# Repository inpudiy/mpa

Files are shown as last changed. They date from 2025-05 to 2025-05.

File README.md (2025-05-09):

# MPA

MPA is a 42-key split keyboard built on the CHOC V1 platform using Chocfox spacing.

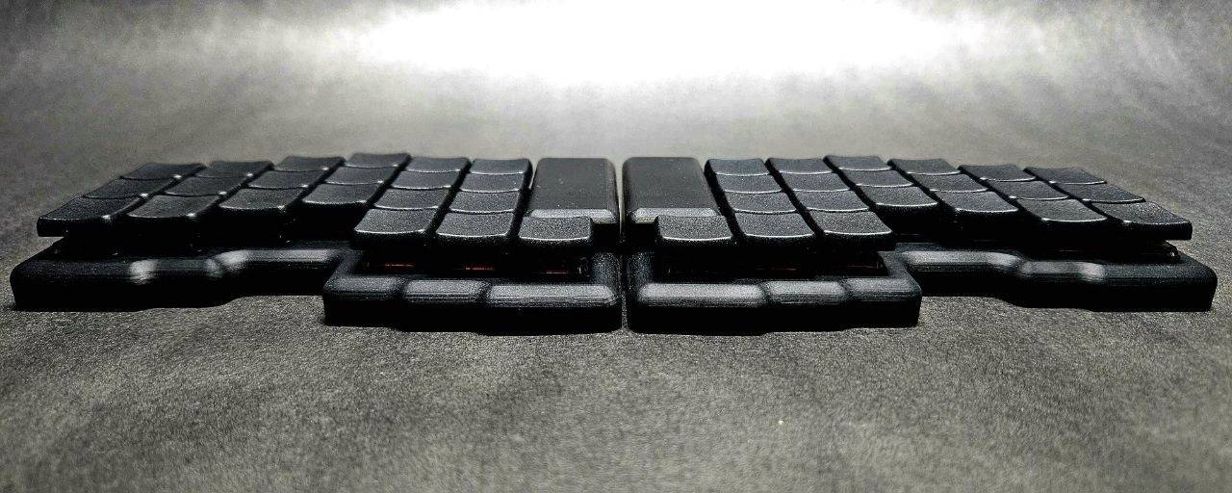
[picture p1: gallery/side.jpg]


[Build Guide](https://github.com/inpudiy/mpa/blob/main/build_guide.md) - [ZMK Firmware](https://github.com/inpudiy/mpa_zmk-config/releases)

## Features

- Supports Chocfox spacing (17.5 × 17.5 mm)  
- Optimized for wireless: hardware power switch, reset button, battery solder pads, no LEDs, and ZMK firmware  
- 42-key layout with an aggressive column-stagger inspired by the Jian keyboard  
- CHOC V1 switches only  
- Pro Micro format microcontroller Compatible with hot-swap installation  
- 3D-printed case  

---

## Bill of Materials (BOM)

| Component | Qty |
| --- | --- |
| Microcontroller: nRFMicro / Super Mini nRF52840 / nice!nano  | 2 |
| Power switch: SUNGMUN BSI-10H | 2 |
| 301230 battery | 2 |
| Turtle Switch SMD 2-pin (3 × 4 × 2 mm) | 2 |
| Silicone bumpers (6 × 2 mm) | 4 |
| Pin Header Female 13 pin (2.54mm) | 4 | 
| Plastic heat-set insert nut M2 (OD 3.2 mm, length 3 mm) | 14  |
| Countersunk head screw M2 (length 4 mm) | 14  |
| PG1350 hot-swap socket | 42  |
| Diode 1N4148W (SOD-323) | 42  |
| CHOC V1 switches | 42  |
| Chocfox 1U keycaps | 42  |

## PCB Image

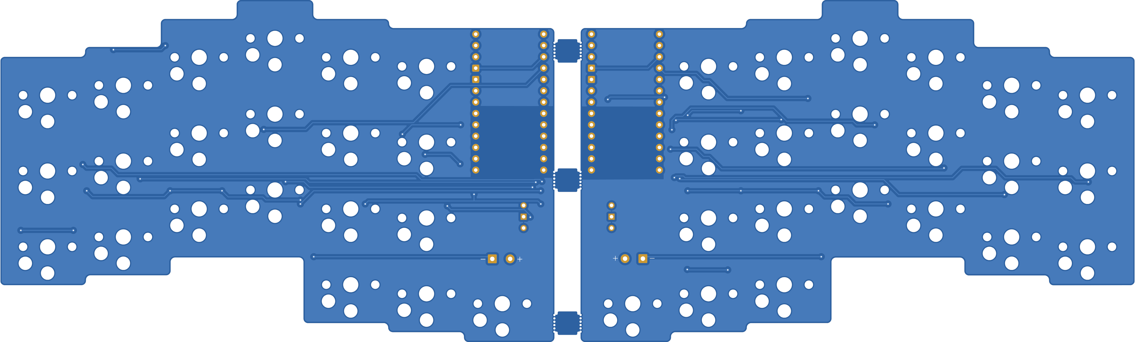
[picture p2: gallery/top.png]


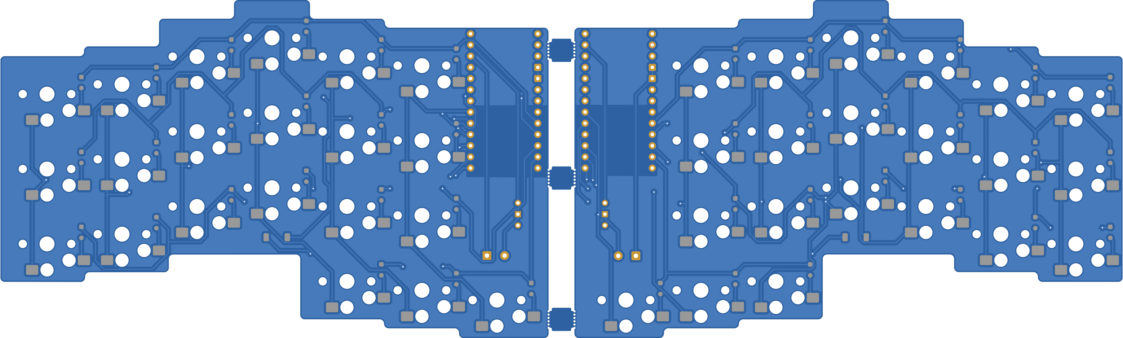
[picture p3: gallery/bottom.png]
Bottom


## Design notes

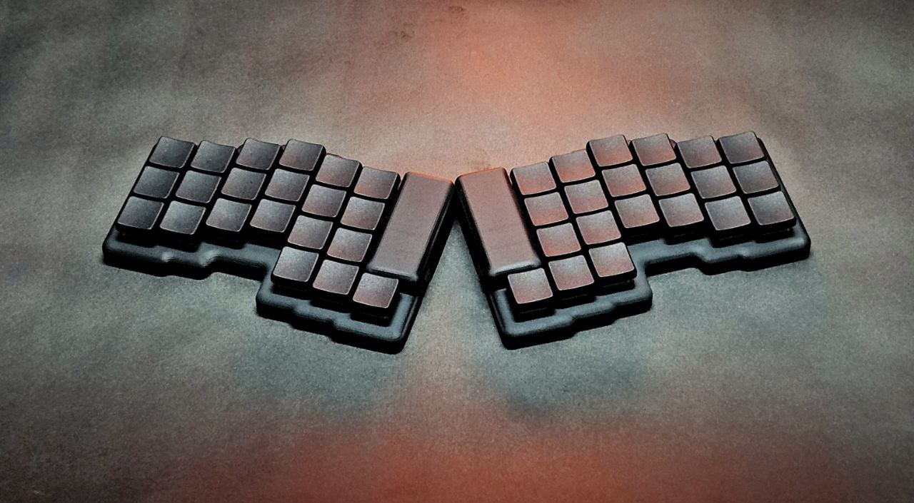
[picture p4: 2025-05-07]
gallery/top.jpg

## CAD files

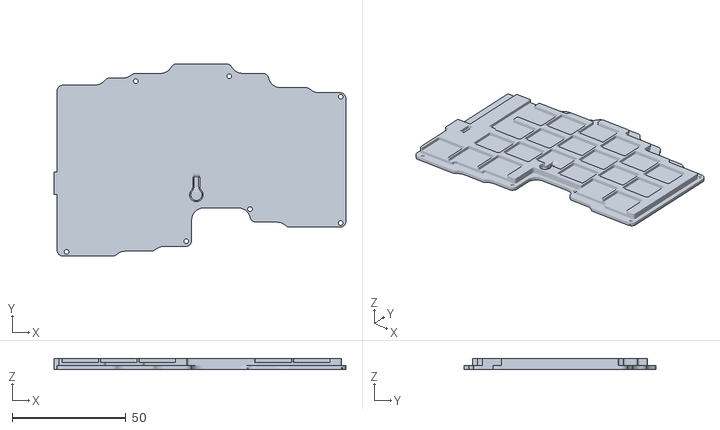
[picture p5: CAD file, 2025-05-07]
case/bottomRight.stl
128.6 x 84.7 x 4.70

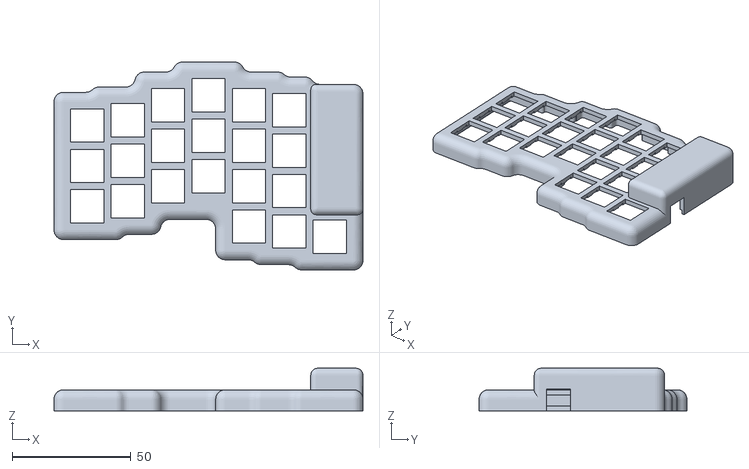
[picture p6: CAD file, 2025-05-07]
case/topLeft.stl
130.0 x 87.4 x 17.9

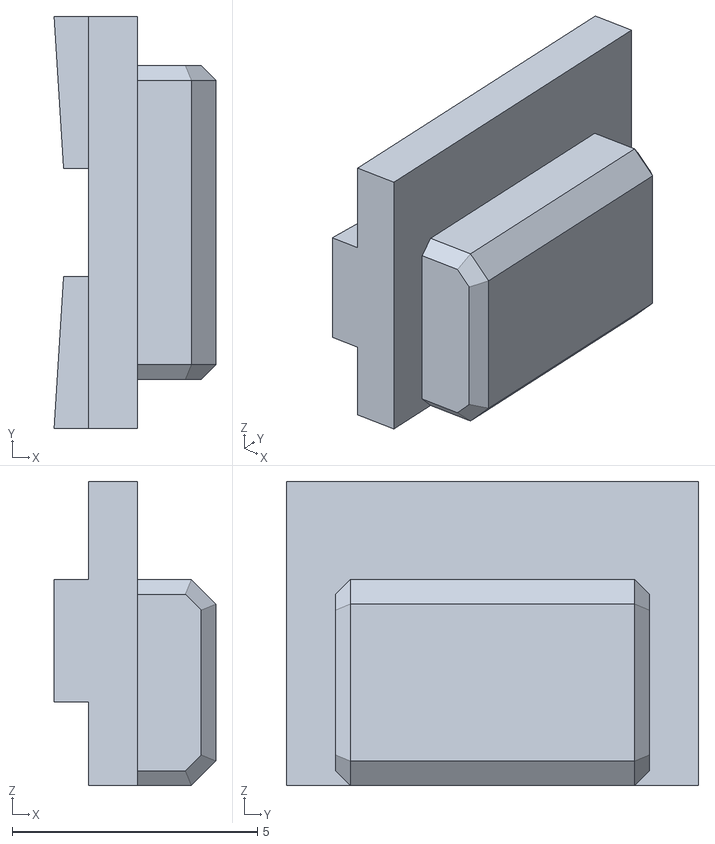
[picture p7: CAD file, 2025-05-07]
case/powerslide.stl
3.30 x 8.40 x 6.20

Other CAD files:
case/topRight.stl
case/bottomLeft.stl

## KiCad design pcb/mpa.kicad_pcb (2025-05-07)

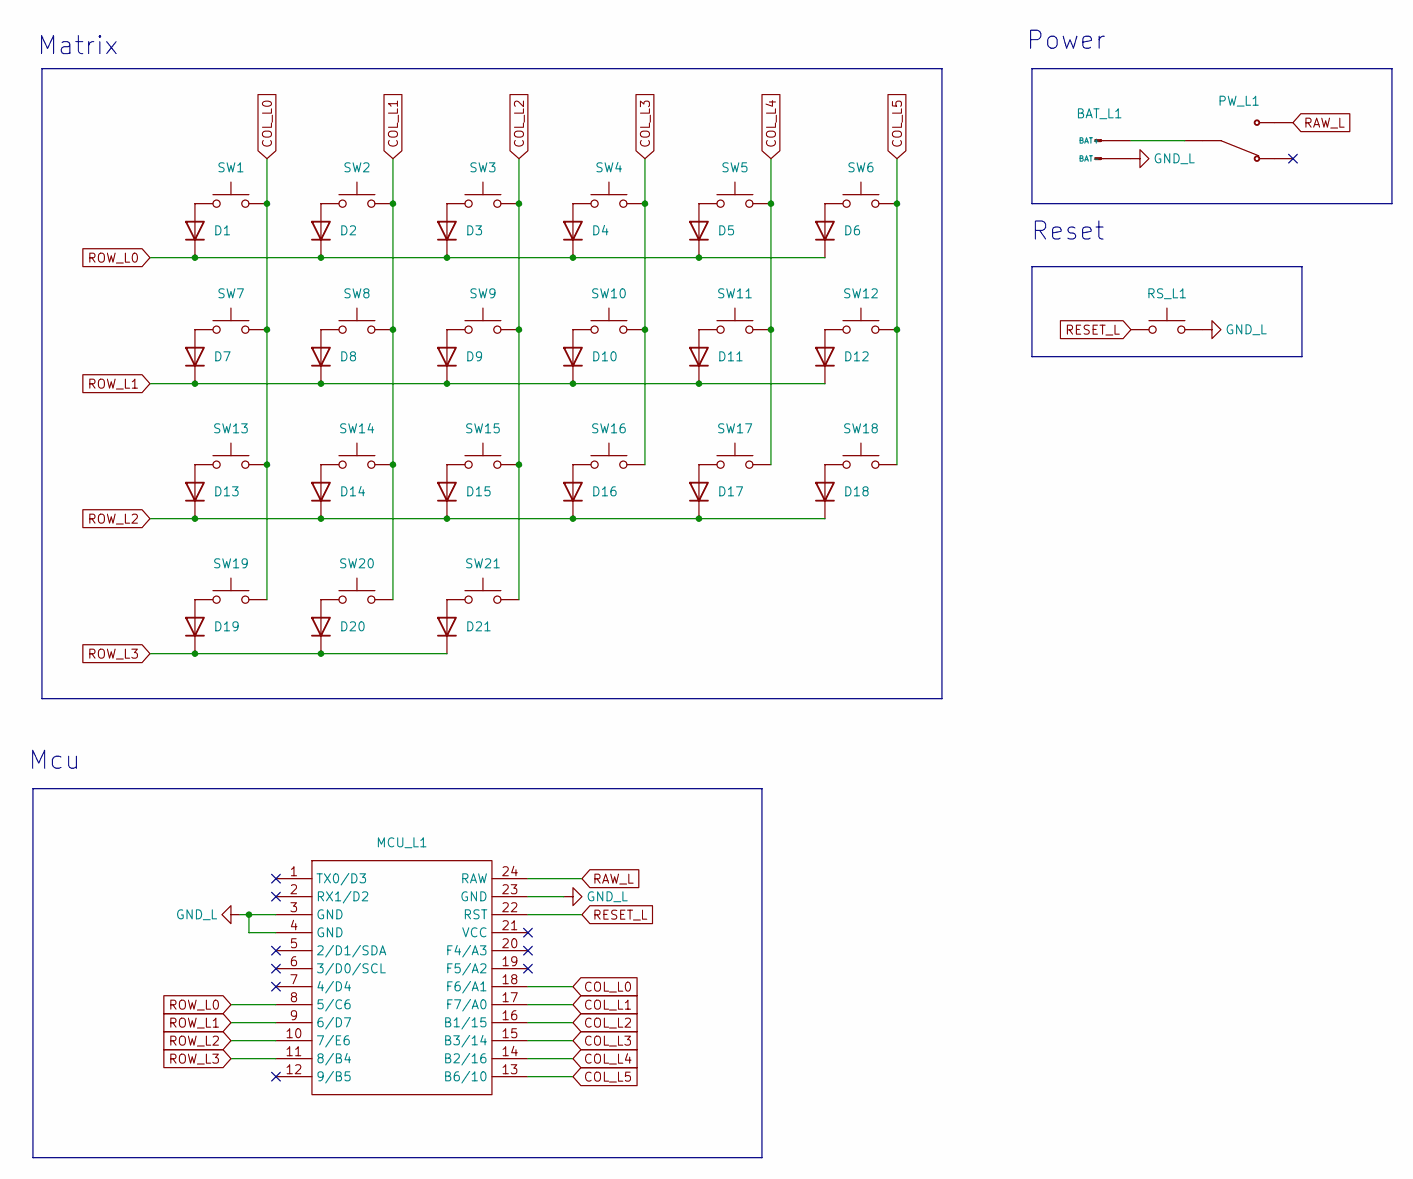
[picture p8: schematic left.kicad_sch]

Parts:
BAT_L1: Battery
D1, D2, D3, D4, D5, D6, D7, D8, D9, D10, D11, D12, D13, D14, D15, D16, D17, D18, D19, D20, D21: Diode; SOD323
MCU_L1: ProMicro_NN
PW_L1: BSI-10H
RS_L1: Reset
SW1, SW2, SW3, SW4, SW5, SW6, SW7, SW8, SW9, SW10, SW11, SW12, SW13, SW14, SW15, SW16, SW17, SW18, SW19, SW20, SW21: Kailh PG1350

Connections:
COL_L0: MCU_L1.18 (F6/A1), SW1.2, SW7.2, SW13.2, SW19.2
COL_L1: MCU_L1.17 (F7/A0), SW2.2, SW8.2, SW14.2, SW20.2
COL_L2: MCU_L1.16 (B1/15), SW3.2, SW9.2, SW15.2, SW21.2
COL_L3: MCU_L1.15 (B3/14), SW4.2, SW10.2, SW16.2
COL_L4: MCU_L1.14 (B2/16), SW5.2, SW11.2, SW17.2
COL_L5: MCU_L1.13 (B6/10), SW6.2, SW12.2, SW18.2
GND_L: BAT_L1.2 (BAT-), MCU_L1.3 (GND), MCU_L1.4 (GND), MCU_L1.23 (GND), RS_L1.2
unnamed: BAT_L1.1 (BAT+), PW_L1.1
unnamed: D1.2 (A), SW1.1
unnamed: D2.2 (A), SW2.1
unnamed: D3.2 (A), SW3.1
unnamed: D4.2 (A), SW4.1
unnamed: D5.2 (A), SW5.1
unnamed: D6.2 (A), SW6.1
unnamed: D7.2 (A), SW7.1
unnamed: D8.2 (A), SW8.1
unnamed: D9.2 (A), SW9.1
unnamed: D10.2 (A), SW10.1
unnamed: D11.2 (A), SW11.1
unnamed: D12.2 (A), SW12.1
unnamed: D13.2 (A), SW13.1
unnamed: D14.2 (A), SW14.1
unnamed: D15.2 (A), SW15.1
unnamed: D16.2 (A), SW16.1
unnamed: D17.2 (A), SW17.1
unnamed: D18.2 (A), SW18.1
unnamed: D19.2 (A), SW19.1
unnamed: D20.2 (A), SW20.1
unnamed: D21.2 (A), SW21.1
RAW_L: MCU_L1.24 (RAW), PW_L1.2
RESET_L: MCU_L1.22 (RST), RS_L1.1
ROW_L0: D1.1 (K), D2.1 (K), D3.1 (K), D4.1 (K), D5.1 (K), D6.1 (K), MCU_L1.8 (5/C6)
ROW_L1: D7.1 (K), D8.1 (K), D9.1 (K), D10.1 (K), D11.1 (K), D12.1 (K), MCU_L1.9 (6/D7)
ROW_L2: D13.1 (K), D14.1 (K), D15.1 (K), D16.1 (K), D17.1 (K), D18.1 (K), MCU_L1.10 (7/E6)
ROW_L3: D19.1 (K), D20.1 (K), D21.1 (K), MCU_L1.11 (8/B4)

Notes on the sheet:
Power
Matrix
Reset
Mcu

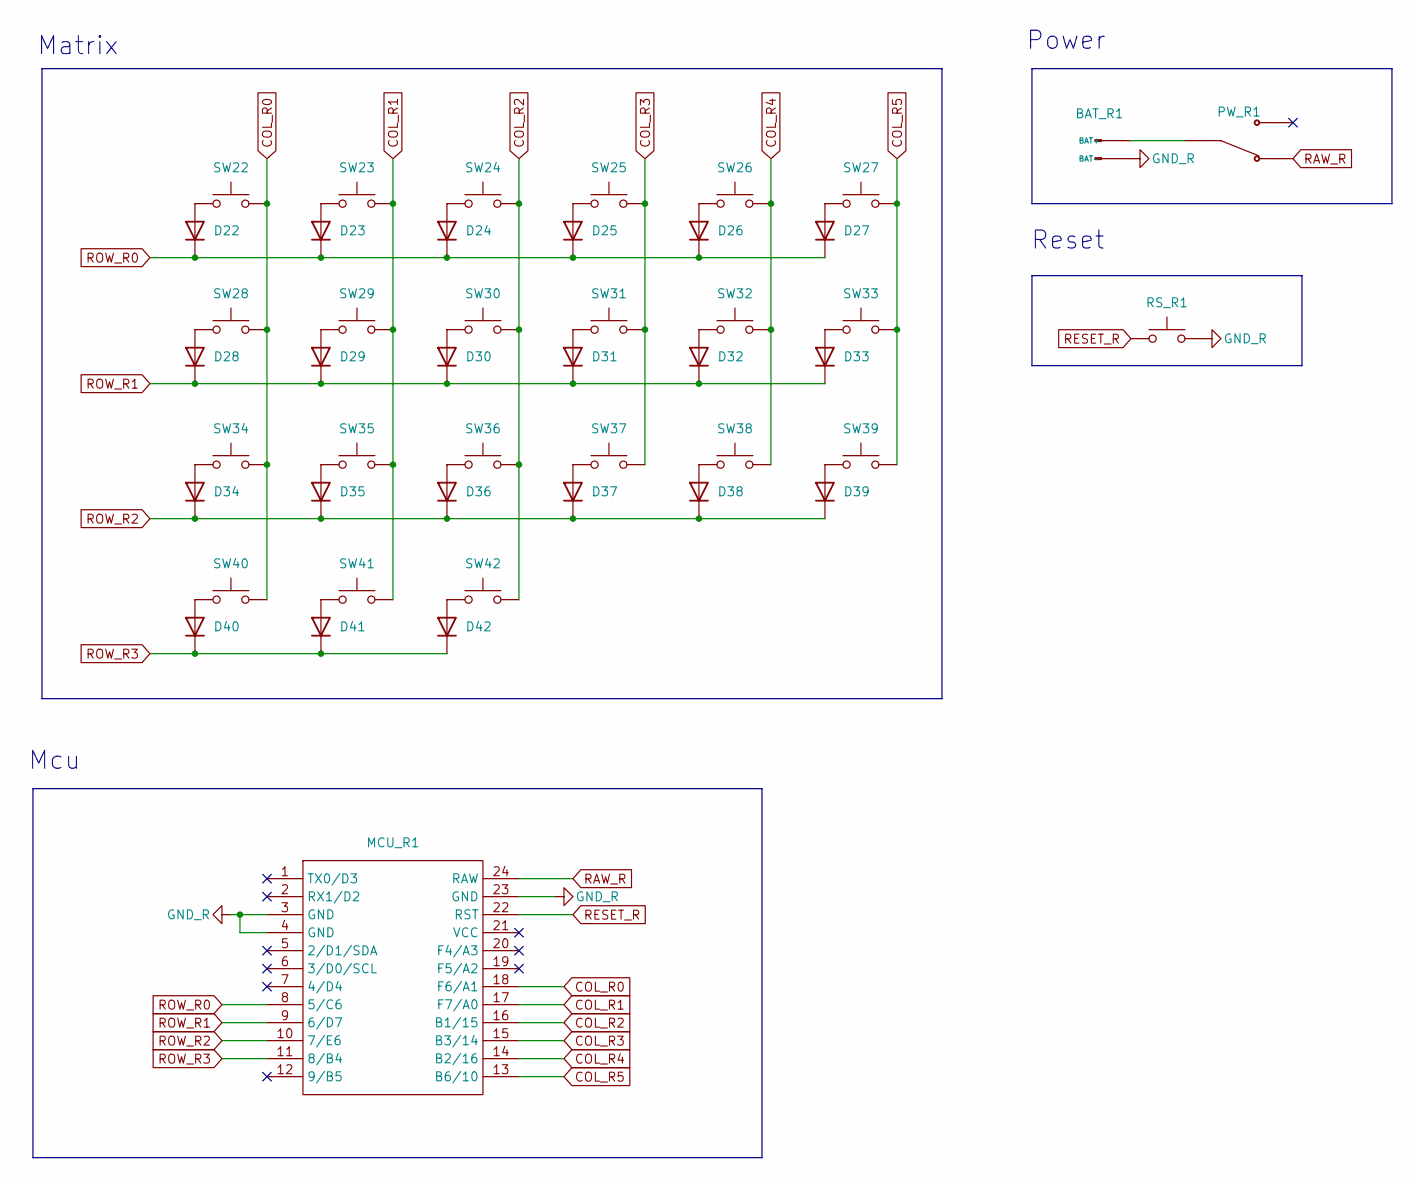
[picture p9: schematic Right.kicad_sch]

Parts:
BAT_R1: Battery
D22, D23, D24, D25, D26, D27, D28, D29, D30, D31, D32, D33, D34, D35, D36, D37, D38, D39, D40, D41, D42: Diode; SOD323
MCU_R1: ProMicro_NN
PW_R1: BSI-10H
RS_R1: Reset
SW22, SW23, SW24, SW25, SW26, SW27, SW28, SW29, SW30, SW31, SW32, SW33, SW34, SW35, SW36, SW37, SW38, SW39, SW40, SW41, SW42: Kailh PG1350

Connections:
COL_R0: MCU_R1.18 (F6/A1), SW22.2, SW28.2, SW34.2, SW40.2
COL_R1: MCU_R1.17 (F7/A0), SW23.2, SW29.2, SW35.2, SW41.2
COL_R2: MCU_R1.16 (B1/15), SW24.2, SW30.2, SW36.2, SW42.2
COL_R3: MCU_R1.15 (B3/14), SW25.2, SW31.2, SW37.2
COL_R4: MCU_R1.14 (B2/16), SW26.2, SW32.2, SW38.2
COL_R5: MCU_R1.13 (B6/10), SW27.2, SW33.2, SW39.2
GND_R: BAT_R1.2 (BAT-), MCU_R1.3 (GND), MCU_R1.4 (GND), MCU_R1.23 (GND), RS_R1.2
unnamed: BAT_R1.1 (BAT+), PW_R1.1
unnamed: D22.2 (A), SW22.1
unnamed: D23.2 (A), SW23.1
unnamed: D24.2 (A), SW24.1
unnamed: D25.2 (A), SW25.1
unnamed: D26.2 (A), SW26.1
unnamed: D27.2 (A), SW27.1
unnamed: D28.2 (A), SW28.1
unnamed: D29.2 (A), SW29.1
unnamed: D30.2 (A), SW30.1
unnamed: D31.2 (A), SW31.1
unnamed: D32.2 (A), SW32.1
unnamed: D33.2 (A), SW33.1
unnamed: D34.2 (A), SW34.1
unnamed: D35.2 (A), SW35.1
unnamed: D36.2 (A), SW36.1
unnamed: D37.2 (A), SW37.1
unnamed: D38.2 (A), SW38.1
unnamed: D39.2 (A), SW39.1
unnamed: D40.2 (A), SW40.1
unnamed: D41.2 (A), SW41.1
unnamed: D42.2 (A), SW42.1
RAW_R: MCU_R1.24 (RAW), PW_R1.3
RESET_R: MCU_R1.22 (RST), RS_R1.1
ROW_R0: D22.1 (K), D23.1 (K), D24.1 (K), D25.1 (K), D26.1 (K), D27.1 (K), MCU_R1.8 (5/C6)
ROW_R1: D28.1 (K), D29.1 (K), D30.1 (K), D31.1 (K), D32.1 (K), D33.1 (K), MCU_R1.9 (6/D7)
ROW_R2: D34.1 (K), D35.1 (K), D36.1 (K), D37.1 (K), D38.1 (K), D39.1 (K), MCU_R1.10 (7/E6)
ROW_R3: D40.1 (K), D41.1 (K), D42.1 (K), MCU_R1.11 (8/B4)

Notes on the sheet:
Mcu
Power
Reset
Matrix

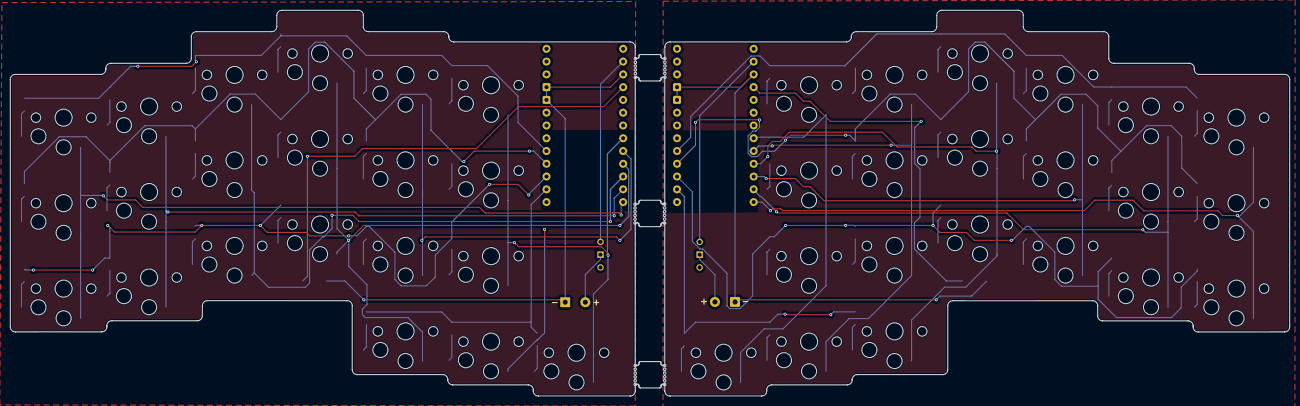
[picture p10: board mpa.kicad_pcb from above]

Board: 2 copper layers, 254.4 x 76.7 mm, 98 parts (0 on the bottom side), 70 nets.

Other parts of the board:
Hole: Hole
Hole#2, Hole#3, Hole#4, Hole#5, Hole#6: Hole

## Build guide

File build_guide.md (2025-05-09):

# Build Guide

This build guide assumes that you already have soldering skills. It will only describe the locations and nuances of component installation

## 1. Break off the chips

There are 3 islands between the board halves, they are not needed during assembly. So gently press on one half of the board to break it in half, and then break off the island from the other half of the board with pliers or any other convenient way

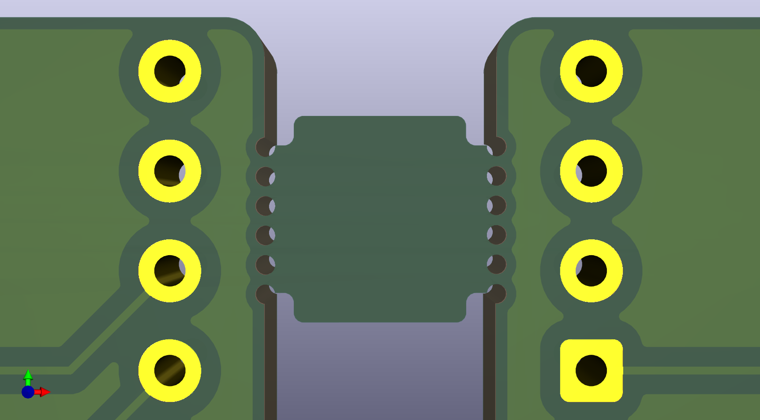
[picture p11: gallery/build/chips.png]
chips


## 2. Diodes

There are 21 diode pads each on the back of the board. Apply flux and place the diodes cathode to square pad and anode to round pad and solder

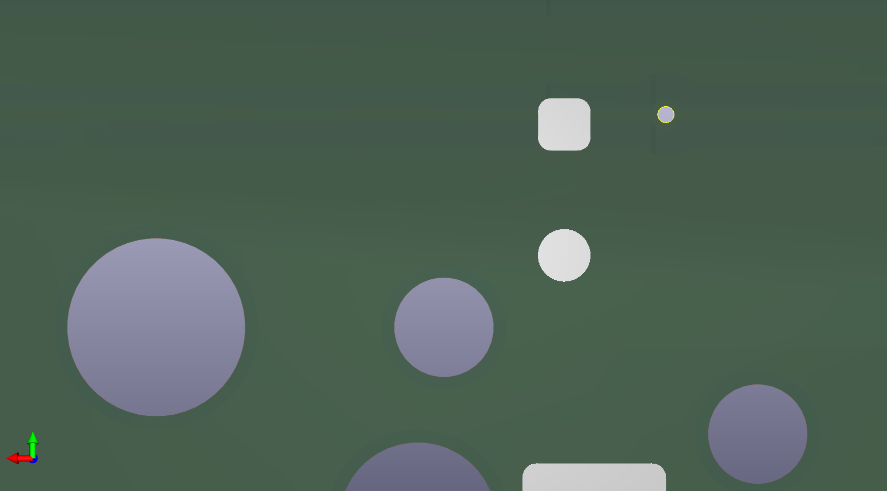
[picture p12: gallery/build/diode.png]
diode


## 3. Hotswap socket

At the bottom of the diodes are the pads for the hotswap sockets. Apply flux and solder them on

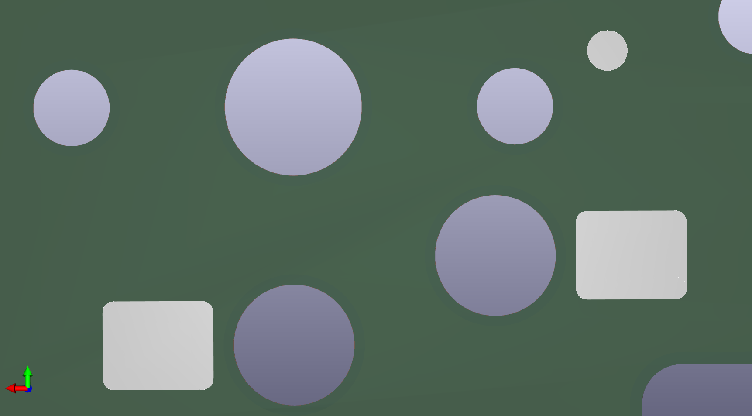
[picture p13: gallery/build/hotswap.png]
hotswap


## 4. Reset button

On the bottom of the board on both halves, install a 3 × 4 × 2 mm Turtle Switch to reset the firmware

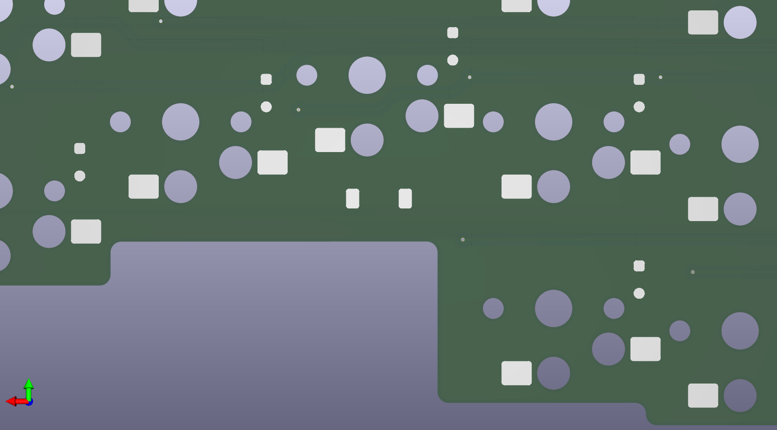
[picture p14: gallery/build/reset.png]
reset


## 5. On-off switch

On the TOP side of the board of both halves, install BSI-10H 

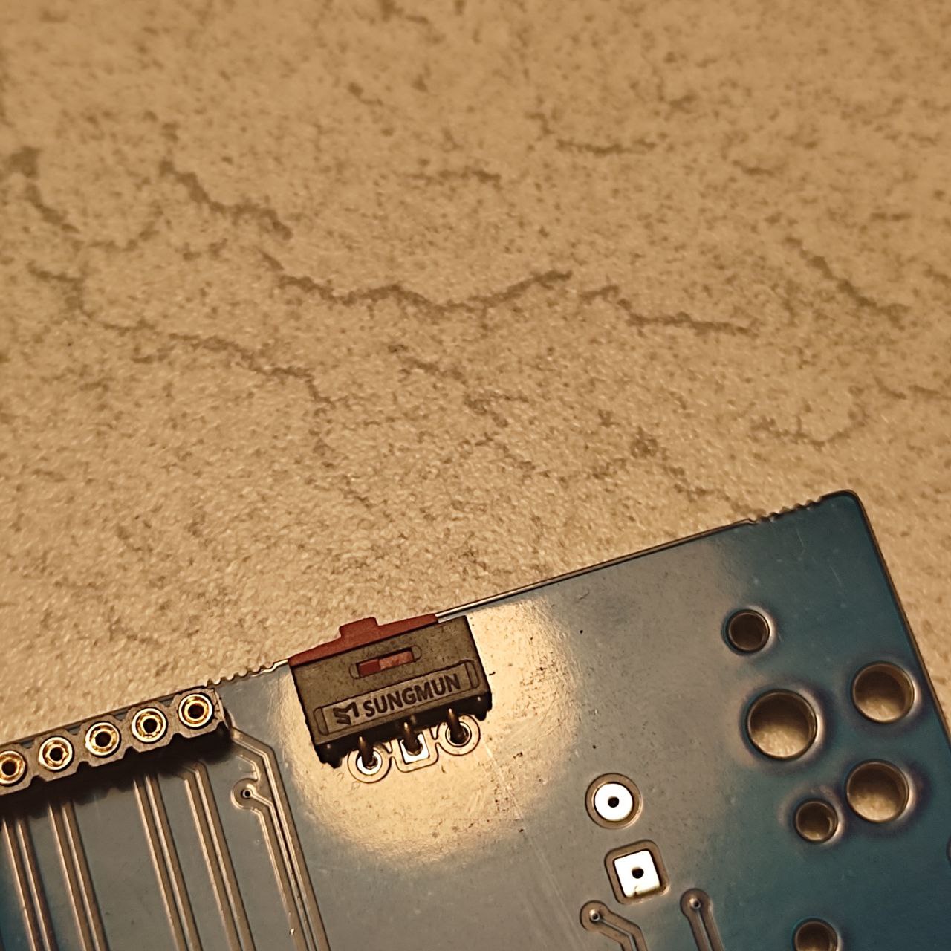
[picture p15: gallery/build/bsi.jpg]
bsi


## 6. Pin Header Female 13 pin

Break off 4 pieces of 13 pins from the long 2.54mm Pin Header Female Single Row 40 Pin and install them on the top side of the board. Carefully flip the board over with them and solder them to the back side of the board

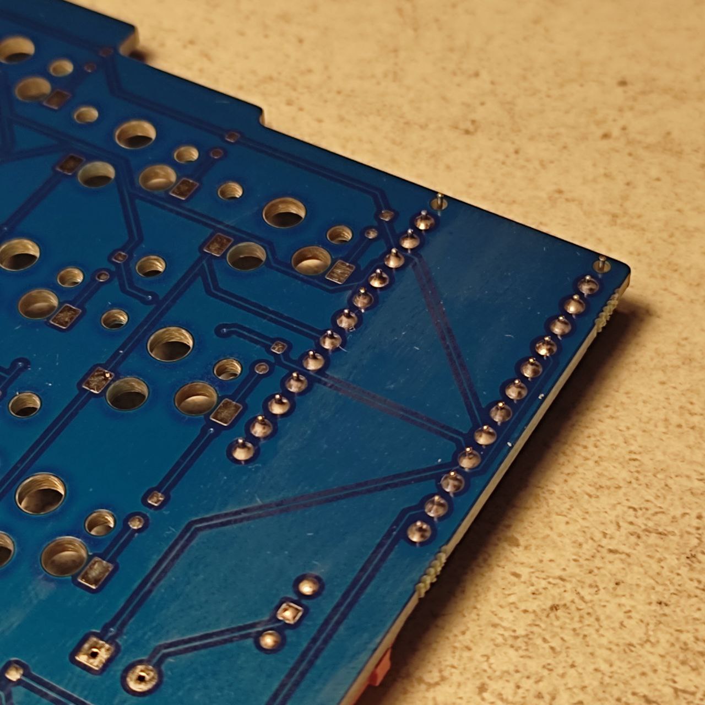
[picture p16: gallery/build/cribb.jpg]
cribb

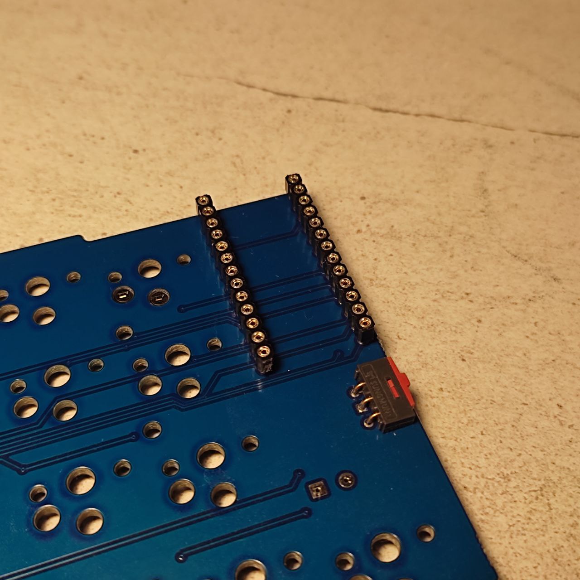
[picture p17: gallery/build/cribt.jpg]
cribt


## 7. Microcontroller

Using wire, diode legs or male heads, solder the board with the microcontroller into the pro micro formfactor with the controller facing upwards

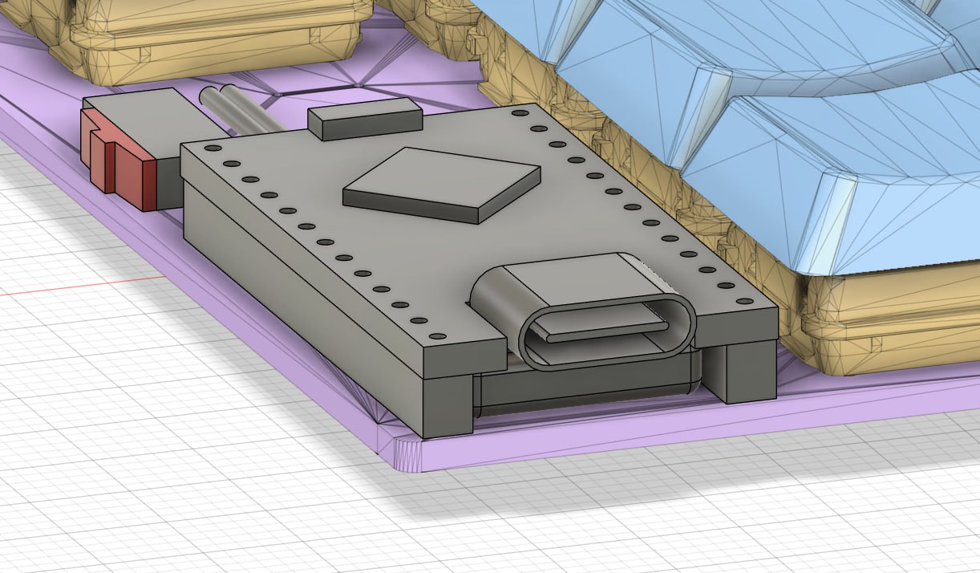
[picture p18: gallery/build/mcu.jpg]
mcu


## 8. Battery

In the last soldering step, solder the wires of the batterjack to the pads and position it under the controller

> [!WARNING]
> Be careful and check with a multimeter that the BSI-10H is in the off state before soldering the battery

## 9. Case

Install the float nuts in the top of the case, install the extension for the switch, install the bottom by screwing it on and glue the non-slip rubber bands on the bottom
